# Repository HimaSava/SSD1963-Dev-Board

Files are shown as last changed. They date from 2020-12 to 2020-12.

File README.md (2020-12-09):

# SSD1963-Dev-Board

SSD1963 is a cheap LCD display chip. It is easy to use and it is preety cheap when compared to the others out there.
Unluckyly being cheap comes with it's flaws. The chip comes in a 128 pin QFP and is hard for beginners to solder without the right tools. But the biggest issue is PCB layout. Unless you are cutting corners on decaps the chip needs 40 seperate D-Caps.
And the worst part there is no guidelines of a dev board with any kind of layout out there to help the beginners.
Well through multiple revisions and sheer luck I designed the whole dev board and had it manufactured and tested.
To my surprise it works with out any hitchs. So I am sharing the files here. 

## Now some specs on the actual Dev Board:
It has the SSD1963 chip and also has the TSC2046 Touch Sensor chip.

The dev board was designed with a particular display(resistive touch) in mind and I have attached the datasheet for it. Based on your display you may need to change the LCD connector.

In interfacing the SSD1963 is used in 8080 mode(Check datasheet) and the touch sensor uses SPI protocol. For now I have added a FRC connector with all the pins that are needed to drive the board, if you want to change it be my guest.

Right now I am still making modifications to the board, so expect some changes in the future and also ping me if you have any suggestions.

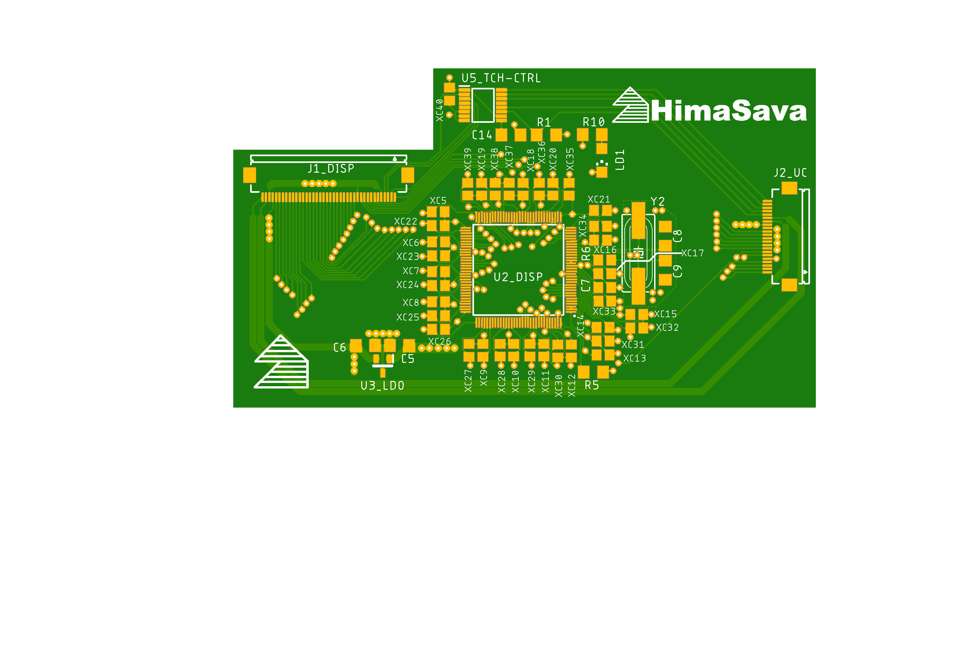
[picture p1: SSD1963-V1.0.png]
Development Board


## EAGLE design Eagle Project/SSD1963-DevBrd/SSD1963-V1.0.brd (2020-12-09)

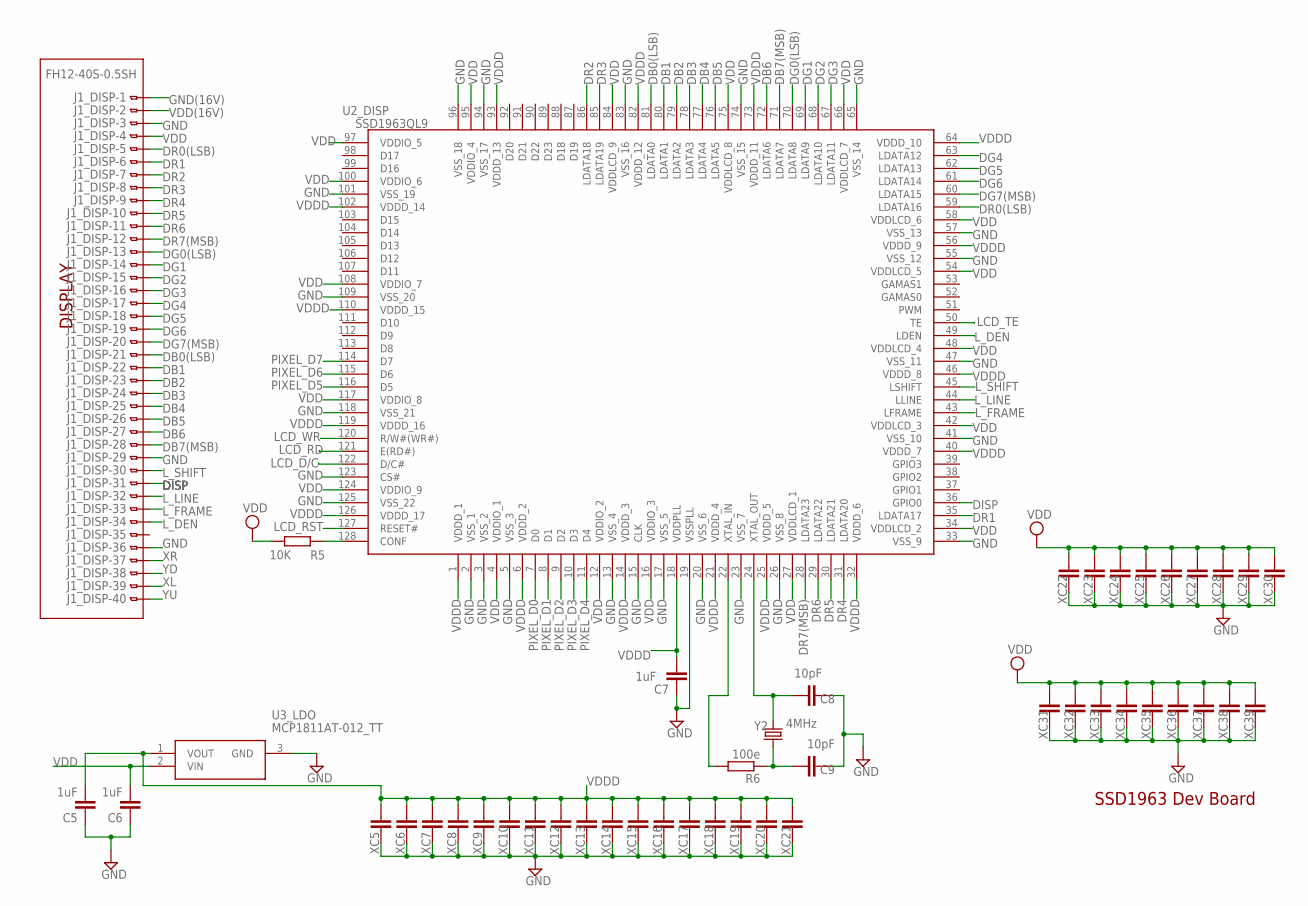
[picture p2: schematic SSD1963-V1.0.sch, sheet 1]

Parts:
C5, C6: 1uF; C1206
C7: 1uF; C0805
C8, C9: 10pF; C1206
J1_DISP: FH12-40S-0.5SH
R5: 10K; R1206
R6: 100e; R0805
U2_DISP: SSD1963QL9; QFP40P1600X1600X160-128N
U3_LDO: MCP1811AT-012_TT; SOT95P237X112-3N
XC5, XC6, XC7, XC8, XC9, XC10, XC11, XC12, XC13, XC14, XC15, XC16, XC17, XC18, XC19, XC20, XC21, XC22, XC23, XC24, XC25, XC26, XC27, XC28, XC29, XC30, XC31, XC32, XC33, XC34, XC35, XC36, XC37, XC38, XC39: 0.1uF; C0805
Y2: 4MHz; HC49UP

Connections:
DB0(LSB): J1_DISP.20, U2_DISP.81 (LDATA0)
DB1: J1_DISP.19, U2_DISP.80 (LDATA1)
DB2: J1_DISP.18, U2_DISP.79 (LDATA2)
DB3: J1_DISP.17, U2_DISP.78 (LDATA3)
DB4: J1_DISP.16, U2_DISP.77 (LDATA4)
DB5: J1_DISP.15, U2_DISP.76 (LDATA5)
DB6: J1_DISP.14, U2_DISP.72 (LDATA6)
DB7(MSB): J1_DISP.13, U2_DISP.71 (LDATA7)
DG0(LSB): J1_DISP.28, U2_DISP.70 (LDATA8)
DG1: J1_DISP.27, U2_DISP.69 (LDATA9)
DG2: J1_DISP.26, U2_DISP.68 (LDATA10)
DG3: J1_DISP.25, U2_DISP.67 (LDATA11)
DG4: J1_DISP.24, U2_DISP.63 (LDATA12)
DG5: J1_DISP.23, U2_DISP.62 (LDATA13)
DG6: J1_DISP.22, U2_DISP.61 (LDATA14)
DG7(MSB): J1_DISP.21, U2_DISP.60 (LDATA15)
DISP: J1_DISP.10, U2_DISP.36 (GPIO0)
DR0(LSB): J1_DISP.36, U2_DISP.59 (LDATA16)
DR1: J1_DISP.35, U2_DISP.35 (LDATA17)
DR2: J1_DISP.34, U2_DISP.86 (LDATA18)
DR3: J1_DISP.33, U2_DISP.85 (LDATA19)
DR4: J1_DISP.32, U2_DISP.31 (LDATA20)
DR5: J1_DISP.31, U2_DISP.30 (LDATA21)
DR6: J1_DISP.30, U2_DISP.29 (LDATA22)
DR7(MSB): J1_DISP.29, U2_DISP.28 (LDATA23)
GND: C5.1, C6.1, C7.1, C8.1, C9.1, J1_DISP.5, J1_DISP.12, J1_DISP.38, U2_DISP.2 (VSS_1), U2_DISP.3 (VSS_2), U2_DISP.5 (VSS_3), U2_DISP.13 (VSS_4), U2_DISP.15 (CLK), U2_DISP.17 (VSS_5), U2_DISP.19 (VSSPLL), U2_DISP.20 (VSS_6), U2_DISP.23 (VSS_7), U2_DISP.26 (VSS_8), U2_DISP.33 (VSS_9), U2_DISP.41 (VSS_10), U2_DISP.47 (VSS_11), U2_DISP.55 (VSS_12), U2_DISP.57 (VSS_13), U2_DISP.65 (VSS_14), U2_DISP.74 (VSS_15), U2_DISP.83 (VSS_16), U2_DISP.94 (VSS_17), U2_DISP.96 (VSS_18), U2_DISP.101 (VSS_19), U2_DISP.109 (VSS_20), U2_DISP.118 (VSS_21), U2_DISP.123 (CS#), U2_DISP.125 (VSS_22), U3_LDO.3 (GND), XC5.1, XC6.1, XC7.1, XC8.1, XC9.1, XC10.1, XC11.1, XC12.1, XC13.1, XC14.1, XC15.1, XC16.1, XC17.1, XC18.1, XC19.1, XC20.1, XC21.1, XC22.1, XC23.1, XC24.1, XC25.1, XC26.1, XC27.1, XC28.1, XC29.1, XC30.1, XC31.1, XC32.1, XC33.1, XC34.1, XC35.1, XC36.1, XC37.1, XC38.1, XC39.1; also elsewhere on the board
GND(16V): J1_DISP.40; also elsewhere on the board
LCD_D/C: U2_DISP.122 (D/C#); also elsewhere on the board
LCD_RD: U2_DISP.121 (E(RD#)); also elsewhere on the board
LCD_RST: U2_DISP.127 (RESET#); also elsewhere on the board
LCD_TE: U2_DISP.50 (TE); also elsewhere on the board
LCD_WR: U2_DISP.120 (R/W#(WR#)); also elsewhere on the board
L_DEN: J1_DISP.7, U2_DISP.49 (LDEN)
L_FRAME: J1_DISP.8, U2_DISP.43 (LFRAME)
L_LINE: J1_DISP.9, U2_DISP.44 (LLINE)
L_SHIFT: J1_DISP.11, U2_DISP.45 (LSHIFT)
unnamed: R5.1, U2_DISP.128 (CONF)
unnamed: C8.2, U2_DISP.24 (XTAL_OUT), Y2.2
unnamed: C9.2, R6.1, Y2.1
unnamed: R6.2, U2_DISP.22 (XTAL_IN)
PIXEL_D0: U2_DISP.7 (D0); also elsewhere on the board
PIXEL_D1: U2_DISP.8 (D1); also elsewhere on the board
PIXEL_D2: U2_DISP.9 (D2); also elsewhere on the board
PIXEL_D3: U2_DISP.10 (D3); also elsewhere on the board
PIXEL_D4: U2_DISP.11 (D4); also elsewhere on the board
PIXEL_D5: U2_DISP.116 (D5); also elsewhere on the board
PIXEL_D6: U2_DISP.115 (D6); also elsewhere on the board
PIXEL_D7: U2_DISP.114 (D7); also elsewhere on the board
VDD: C6.2, J1_DISP.37, R5.2, U2_DISP.4 (VDDIO_1), U2_DISP.12 (VDDIO_2), U2_DISP.16 (VDDIO_3), U2_DISP.27 (VDDLCD_1), U2_DISP.34 (VDDLCD_2), U2_DISP.42 (VDDLCD_3), U2_DISP.48 (VDDLCD_4), U2_DISP.54 (VDDLCD_5), U2_DISP.58 (VDDLCD_6), U2_DISP.66 (VDDLCD_7), U2_DISP.75 (VDDLCD_8), U2_DISP.84 (VDDLCD_9), U2_DISP.95 (VDDIO_4), U2_DISP.97 (VDDIO_5), U2_DISP.100 (VDDIO_6), U2_DISP.108 (VDDIO_7), U2_DISP.117 (VDDIO_8), U2_DISP.124 (VDDIO_9), U3_LDO.2 (VIN), XC22.2, XC23.2, XC24.2, XC25.2, XC26.2, XC27.2, XC28.2, XC29.2, XC30.2, XC31.2, XC32.2, XC33.2, XC34.2, XC35.2, XC36.2, XC37.2, XC38.2, XC39.2; also elsewhere on the board
VDD(16V): J1_DISP.39; also elsewhere on the board
VDDD: C5.2, C7.2, U2_DISP.1 (VDDD_1), U2_DISP.6 (VDDD_2), U2_DISP.14 (VDDD_3), U2_DISP.18 (VDDPLL), U2_DISP.21 (VDDD_4), U2_DISP.25 (VDDD_5), U2_DISP.32 (VDDD_6), U2_DISP.40 (VDDD_7), U2_DISP.46 (VDDD_8), U2_DISP.56 (VDDD_9), U2_DISP.64 (VDDD_10), U2_DISP.73 (VDDD_11), U2_DISP.82 (VDDD_12), U2_DISP.93 (VDDD_13), U2_DISP.102 (VDDD_14), U2_DISP.110 (VDDD_15), U2_DISP.119 (VDDD_16), U2_DISP.126 (VDDD_17), U3_LDO.1 (VOUT), XC5.2, XC6.2, XC7.2, XC8.2, XC9.2, XC10.2, XC11.2, XC12.2, XC13.2, XC14.2, XC15.2, XC16.2, XC17.2, XC18.2, XC19.2, XC20.2, XC21.2
XL: J1_DISP.2; also elsewhere on the board
XR: J1_DISP.4; also elsewhere on the board
YD: J1_DISP.3; also elsewhere on the board
YU: J1_DISP.1; also elsewhere on the board

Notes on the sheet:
DISPLAY
SSD1963 Dev Board

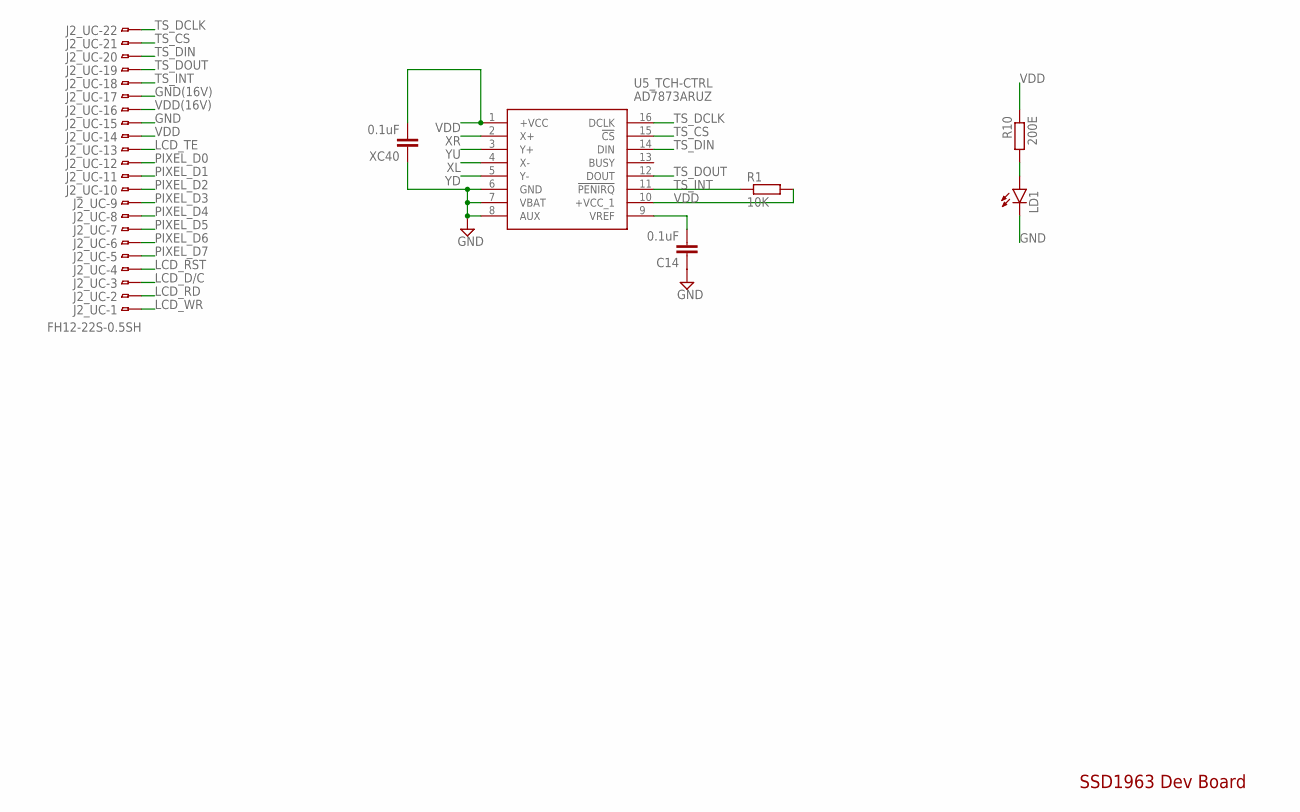
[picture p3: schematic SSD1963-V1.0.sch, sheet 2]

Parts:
C14: 0.1uF; C1206
J2_UC: FH12-22S-0.5SH
LD1: LEDCHIPLED_1206; CHIPLED_1206
R1: 10K; R1206
R10: 200E; R1206
U5_TCH-CTRL: AD7873ARUZ; SOP64P600X175-16N
XC40: 0.1uF; C0805

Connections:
GND: C14.1, J2_UC.15, LD1.C, U5_TCH-CTRL.6 (GND), U5_TCH-CTRL.7 (VBAT), U5_TCH-CTRL.8 (AUX), XC40.1; also elsewhere on the board
GND(16V): J2_UC.17; also elsewhere on the board
LCD_D/C: J2_UC.3; also elsewhere on the board
LCD_RD: J2_UC.2; also elsewhere on the board
LCD_RST: J2_UC.4; also elsewhere on the board
LCD_TE: J2_UC.13; also elsewhere on the board
LCD_WR: J2_UC.1; also elsewhere on the board
unnamed: C14.2, U5_TCH-CTRL.9 (VREF)
unnamed: LD1.A, R10.2
PIXEL_D0: J2_UC.12; also elsewhere on the board
PIXEL_D1: J2_UC.11; also elsewhere on the board
PIXEL_D2: J2_UC.10; also elsewhere on the board
PIXEL_D3: J2_UC.9; also elsewhere on the board
PIXEL_D4: J2_UC.8; also elsewhere on the board
PIXEL_D5: J2_UC.7; also elsewhere on the board
PIXEL_D6: J2_UC.6; also elsewhere on the board
PIXEL_D7: J2_UC.5; also elsewhere on the board
TS_CS: J2_UC.21, U5_TCH-CTRL.15 (!CS)
TS_DCLK: J2_UC.22, U5_TCH-CTRL.16 (DCLK)
TS_DIN: J2_UC.20, U5_TCH-CTRL.14 (DIN)
TS_DOUT: J2_UC.19, U5_TCH-CTRL.12 (DOUT)
TS_INT: J2_UC.18, R1.1, U5_TCH-CTRL.11 (!PENIRQ)
VDD: J2_UC.14, R1.2, R10.1, U5_TCH-CTRL.1 (+VCC), U5_TCH-CTRL.10 (+VCC_1), XC40.2; also elsewhere on the board
VDD(16V): J2_UC.16; also elsewhere on the board
XL: U5_TCH-CTRL.4 (X-); also elsewhere on the board
XR: U5_TCH-CTRL.2 (X+); also elsewhere on the board
YD: U5_TCH-CTRL.5 (Y-); also elsewhere on the board
YU: U5_TCH-CTRL.3 (Y+); also elsewhere on the board

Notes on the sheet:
SSD1963 Dev Board

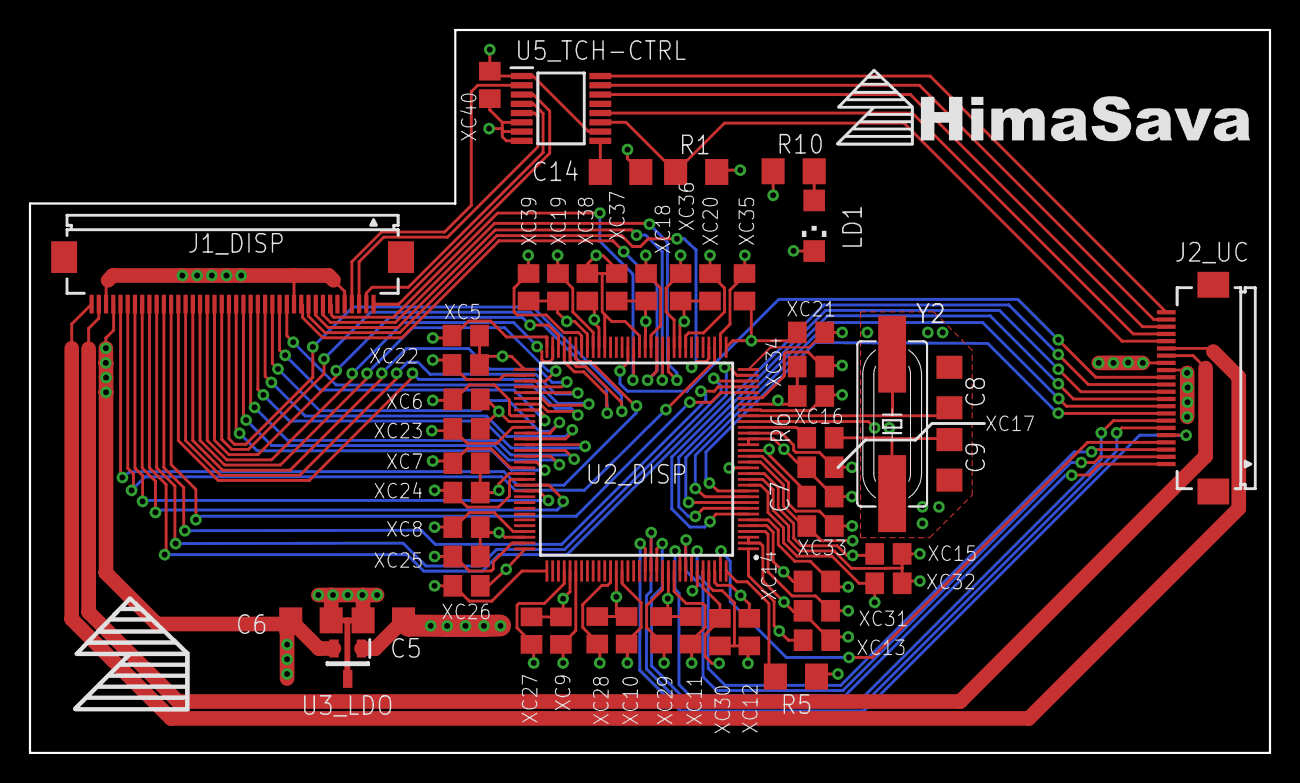
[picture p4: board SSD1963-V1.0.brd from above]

Board: 4 copper layers, 85.8 x 50.0 mm, 53 parts (0 on the bottom side), 62 nets.
